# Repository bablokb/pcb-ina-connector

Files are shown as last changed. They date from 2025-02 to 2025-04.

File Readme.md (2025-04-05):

PCB INA-Connector
=================

This is a support PCB for Adafruit's INA219, INA260 and INA3221
breakouts. Connect the power-source to one of the connectors
on the V-IN side, the load to one of the connectors on the V-OUT
side and the INA-breakout to the screwterminal on the back.

V-IN supports

  - a JST-PH2 connector (typically for a LiPo) or
  - a two-pin DuPont 2.54mm pitch header or
  - a 5.5/2.1mm barrel jack

V-OUT suports

  - an AKL-182 socket or
  - a two-pin DuPont 2.54mm pitch header
    
The AKL-182 socket takes AKL-169 plugs. I use these with various
adapter wires, equiped e.g. with micro-USB, USB-C, JST-PH2 on the
other end.
As an alternative, you could use plain 3.5mm screw-terminals.

The footprint inbetween V-IN and V-OUT is for a mini toggle
switch, e.g.
<https://aliexpress.com/item/1005004692981776.html>.

You should also connect GND of this PCB to the INA-breakout if it
does not share GND somewhere else. Likewise for the INA3221
(which has three channels), use and connect three of these
PCBs:

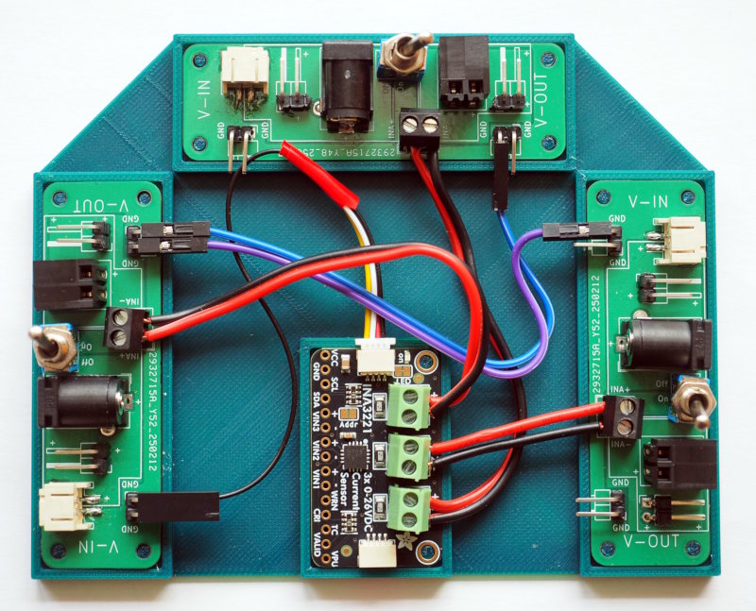
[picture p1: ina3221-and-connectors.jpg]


Schematic
---------

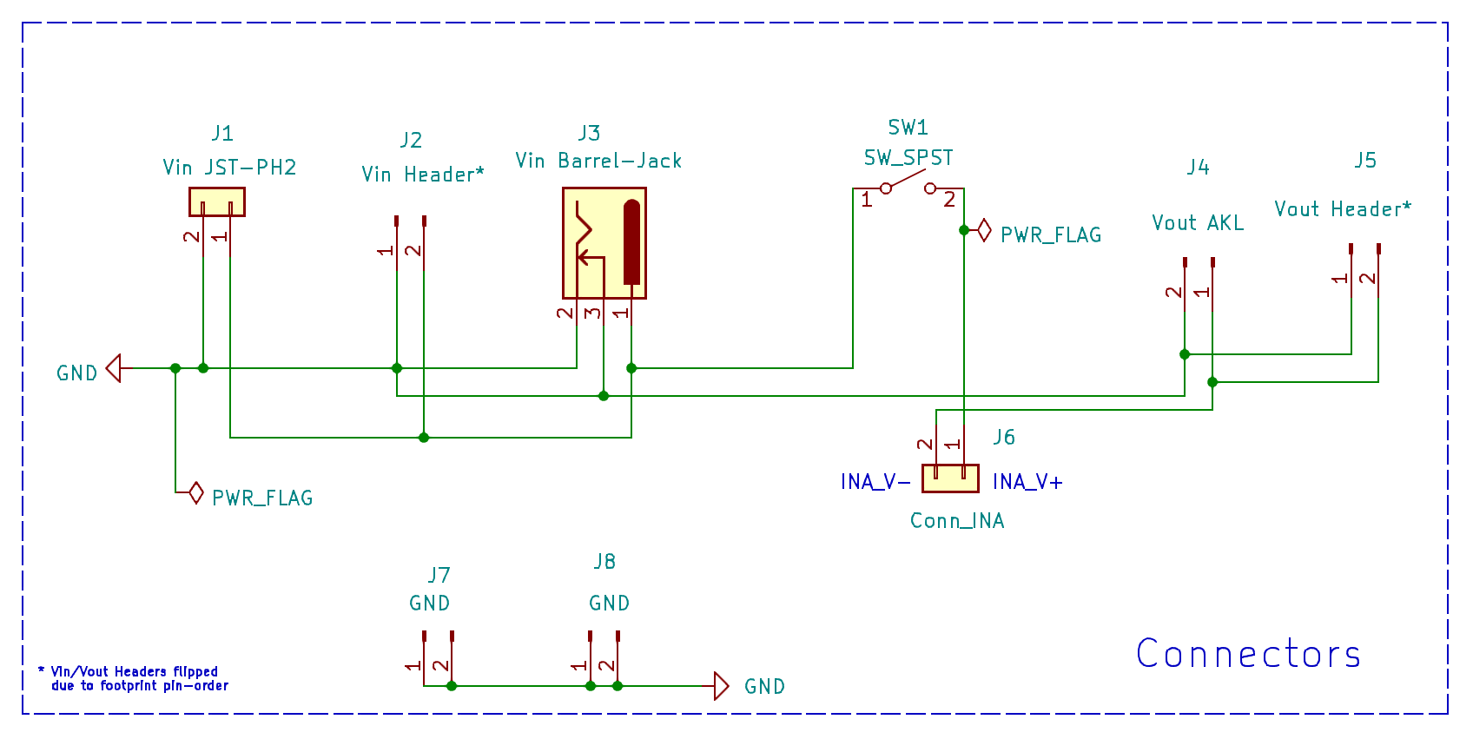
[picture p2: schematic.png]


Layout
------

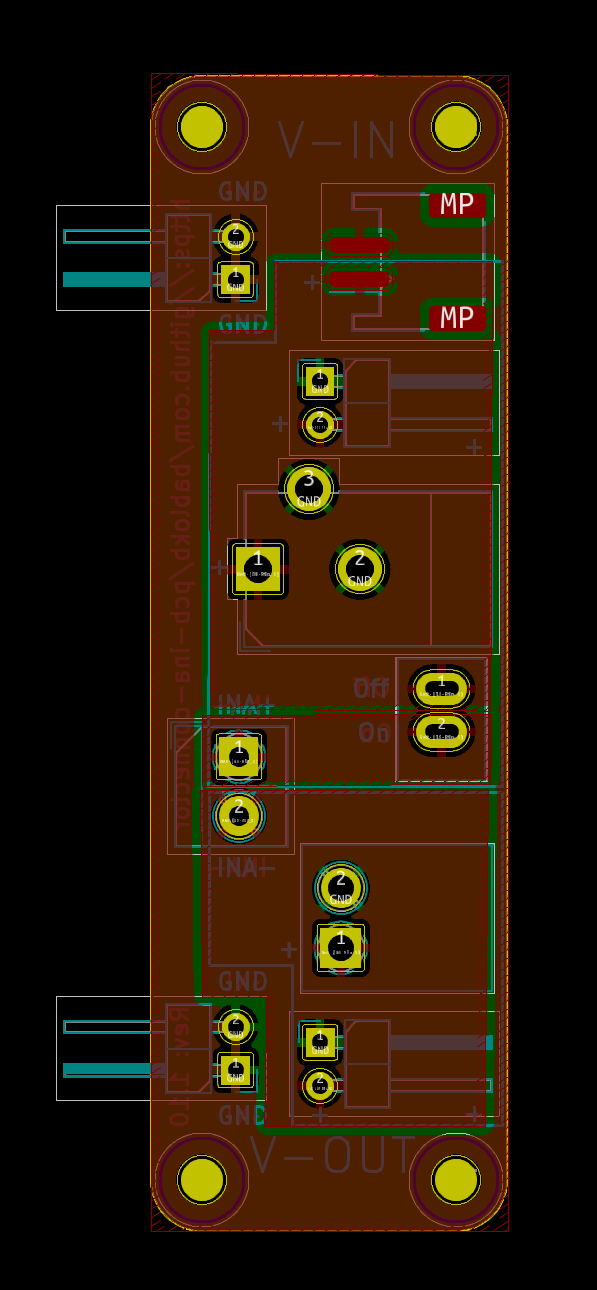
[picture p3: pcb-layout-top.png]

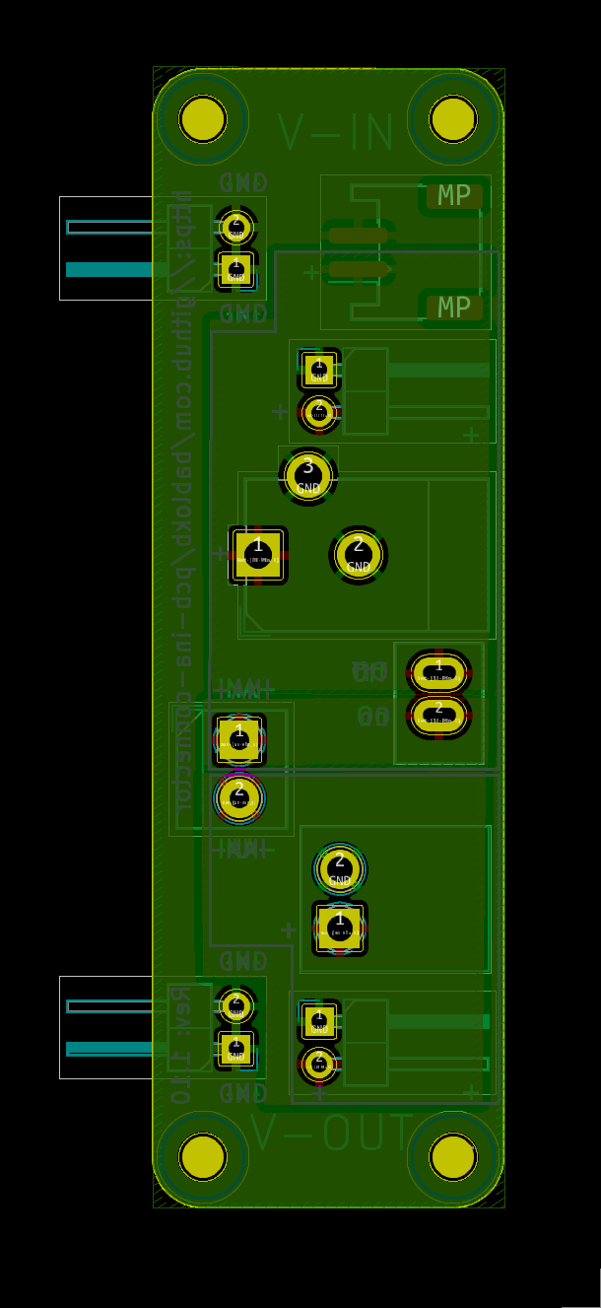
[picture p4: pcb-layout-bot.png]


3D-Views
--------

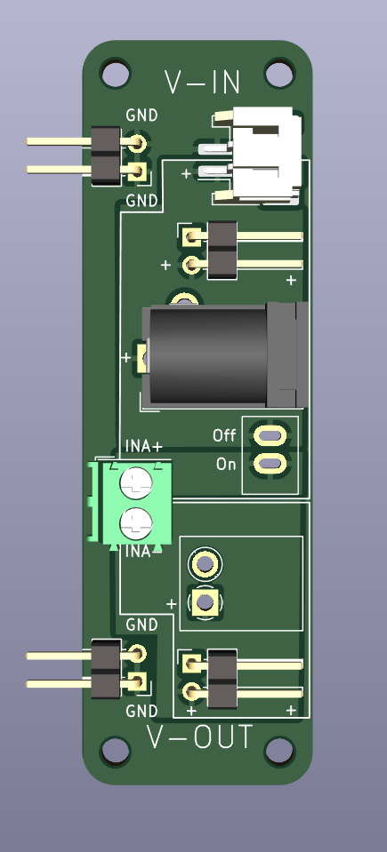
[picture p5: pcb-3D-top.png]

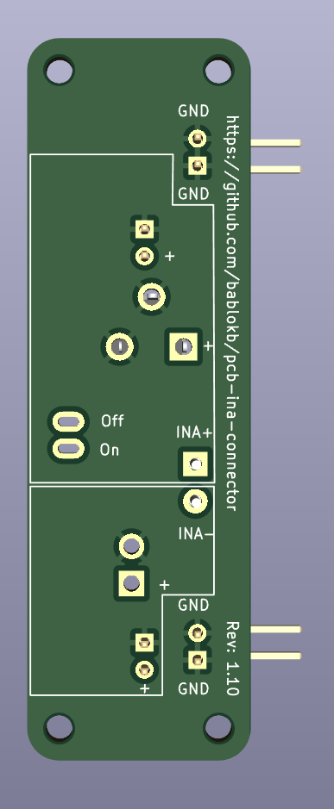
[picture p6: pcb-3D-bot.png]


3D-Model
--------

In the directory `3D` there is an OpenSCAD-model for a
holder that takes an INA3221 and three off the PCBs.

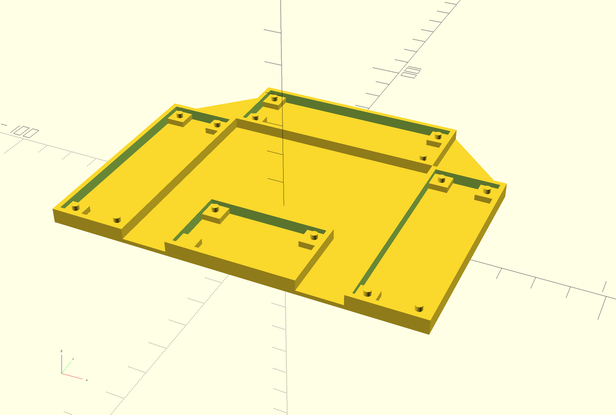
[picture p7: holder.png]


License
-------

[![CC BY-SA 4.0][cc-by-sa-shield]][cc-by-sa]

This work is licensed under a
[Creative Commons Attribution-ShareAlike 4.0 International
License][cc-by-sa].

[][cc-by-sa]

[cc-by-sa]: http://creativecommons.org/licenses/by-sa/4.0/
[cc-by-sa-image]: https://licensebuttons.net/l/by-sa/4.0/88x31.png
[cc-by-sa-shield]:
https://img.shields.io/badge/License-CC%20BY--SA%204.0-lightgrey.svg

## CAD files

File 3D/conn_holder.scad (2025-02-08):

// ---------------------------------------------------------------------------
// 3D-Model (OpenSCAD): enclosure for INA3221-connector.
//
// Author: Bernhard Bablok
// License: GPL3
//
// https://github.com/bablokb/pcb-ina-connector
// ---------------------------------------------------------------------------

include <BOSL2/std.scad>

include <dimensions.scad>
include <pcb_holder.scad>

// dimensions   --------------------------------------------------------------

function conn_holder_x() = 21.0;
function conn_holder_y() = 68.0;

// --- conn_holder   ---------------------------------------------------------

module conn_holder() {
  pcb_holder(x_pcb=conn_holder_x(),
             y_pcb=conn_holder_y());
}

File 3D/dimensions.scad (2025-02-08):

// -----------------------------------------------------------------------------
// 3D-Model (OpenSCAD): generic dimensions.
//
// Author: Bernhard Bablok
// License: GPL3
//
// https://github.com/bablokb/pcb-ina-connector
// ---------------------------------------------------------------------------

$fa = 1;
$fs = 0.4;
$fn= $preview ? 32 : 128;

fuzz = 0.01;
w2 = 0.86;                 // 2 walls
w4 = 1.67;                 // 4 walls
gap = 0.2;                 // gap pcb to case

b = 1.4;               // base thickness

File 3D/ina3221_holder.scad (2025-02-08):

// ---------------------------------------------------------------------------
// 3D-Model (OpenSCAD): enclosure for INA3221-breakout.
//
// Author: Bernhard Bablok
// License: GPL3
//
// https://github.com/bablokb/pcb-ina-connector
// ---------------------------------------------------------------------------

include <BOSL2/std.scad>

include <dimensions.scad>
include <pcb_holder.scad>

// dimensions   --------------------------------------------------------------

function ina3221_holder_x() = 38.354;
function ina3221_holder_y() = 22.86;
function ina3221_holder_s() =  2.54;

// --- ina3221_holder   ------------------------------------------------------

module ina3221_holder() {
  pcb_holder(x_pcb=ina3221_holder_x(),
             y_pcb=ina3221_holder_y(),
             x_screw=ina3221_holder_s(),
             y_screw=ina3221_holder_s(),
             screws=[1,1,0,0]);
}

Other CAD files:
3D/main.scad
3D/pcb_holder.scad

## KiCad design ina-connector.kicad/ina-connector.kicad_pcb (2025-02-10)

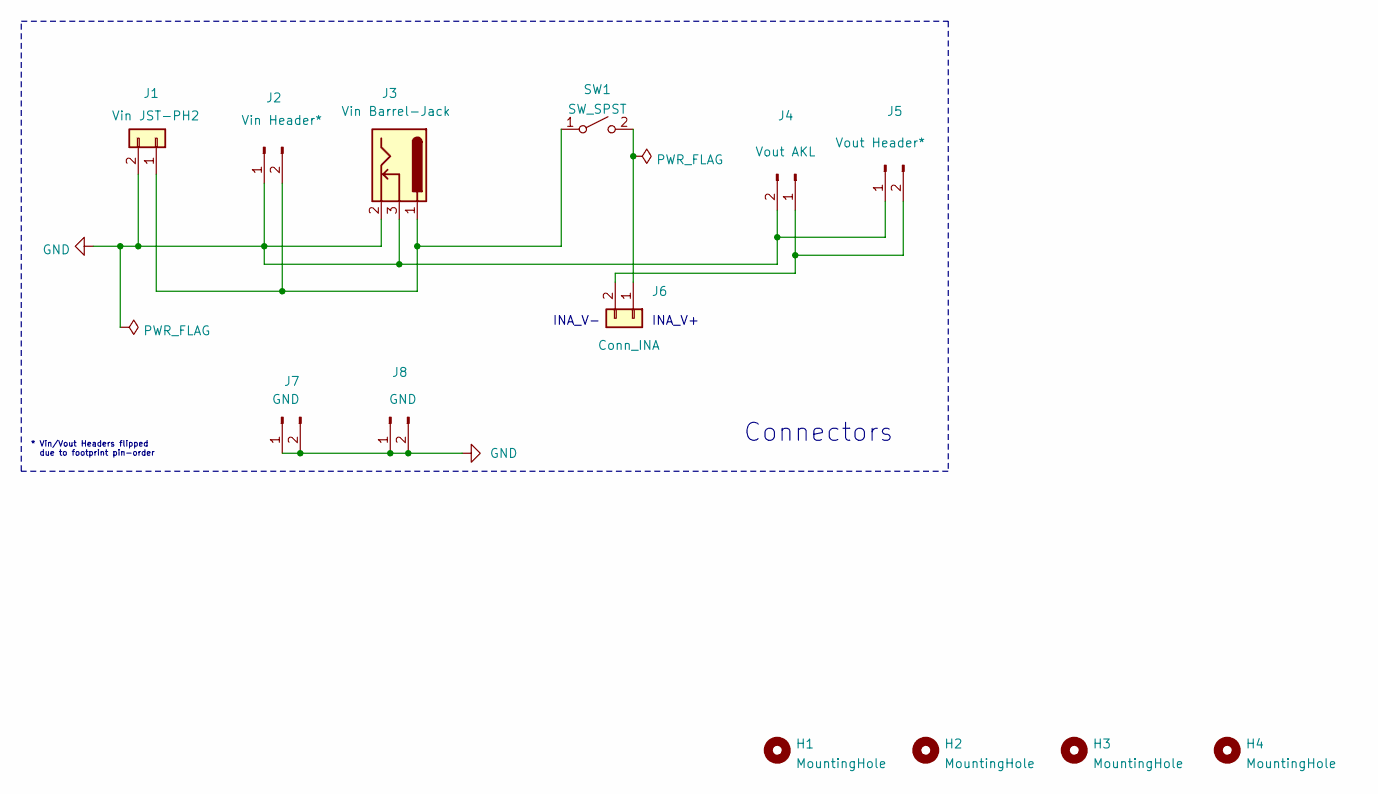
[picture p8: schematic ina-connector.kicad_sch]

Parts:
H1, H2, H3, H4: MountingHole; MountingHole_2.5mm
J1: Vin JST-PH2; JST_PH_S2B-PH-SM4-TB_1x02-1MP_P2.00mm_Horizontal
J2: Vin Header*; PinHeader_1x02_P2.54mm_Horizontal
J3: Vin Barrel-Jack; BarrelJack_CUI_PJ-102AH_Horizontal
J4: Vout AKL; TerminalBlock_MetzConnect_Type182_PT11302HBBN_1x02_P3.50mm_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
J5: Vout Header*; PinHeader_1x02_P2.54mm_Horizontal
J6: Conn_INA; TerminalBlock_MetzConnect_Type059_RT06302HBWC_1x02_P3.50mm_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
J7, J8: GND; PinHeader_1x02_P2.54mm_Horizontal
SW1: SW_SPST; Kippschalter_On-Off

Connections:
GND: J1.2, J2.1, J3.2, J3.3, J4.2, J5.1, J7.1, J7.2, J8.1, J8.2
unnamed: J1.1, J2.2, J3.1, SW1.1 (A)
unnamed: J4.1, J5.2, J6.2
unnamed: J6.1, SW1.2 (B)

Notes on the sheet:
* Vin/Vout Headers flipped due to footprint pin-order
INA_V-
INA_V+
Connectors

Board: 2 copper layers, 13 parts (0 on the bottom side), 4 nets, no tracks yet.

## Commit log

2025-02-08 added 3D model for INA3221 plus 3 connectors
    [conn_holder.scad, dimensions.scad, ina3221_holder.scad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]
2025-02-10 Rev. 1.10: use thermal reliefs
    [ina-connector.kicad_pcb, ina-connector.kicad_sch]
2025-02-19 basic implementation of cover
    [main.scad]
2025-02-19 rotate INA3221-holder, i.e. move the Stemma/Qt connector on the front
    [main.scad]
2025-02-19 add support walls
    [main.scad]
2025-02-19 added cutouts for ina-connectors
    [main.scad]
2025-02-19 added cutouts for switches
    [main.scad]
2025-02-19 add cutout for Stemma/Qt
    [main.scad]
2025-02-20 moved holes for switches a bit
    [main.scad]
2025-02-20 enlarged cutout
    [main.scad]
2025-02-20 enlarge cutouts up to the top
    [main.scad]
2025-02-20 larger cutout for Stemma/Qt
    [main.scad]
2025-02-20 added support for INA3221 screw-terminals
    [main.scad]
2025-04-05 add image of INA3221 with connectors
